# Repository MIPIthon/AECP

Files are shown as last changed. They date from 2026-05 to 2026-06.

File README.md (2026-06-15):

<h1>AECP (Analog Eddy Current Pickup)</h1>
Analog Eddy Current Pickup (AECP) is an analog eddy current signal conditioner circuit based on synchronous rectification of the amplitude of an LC tank circuit at resonance frequency. The circuit can be used to measure e.g. relative movement of a conductive or magnetic permeable object.

<h2>PCBA (Printed Circuit Board Assembly) </h2>

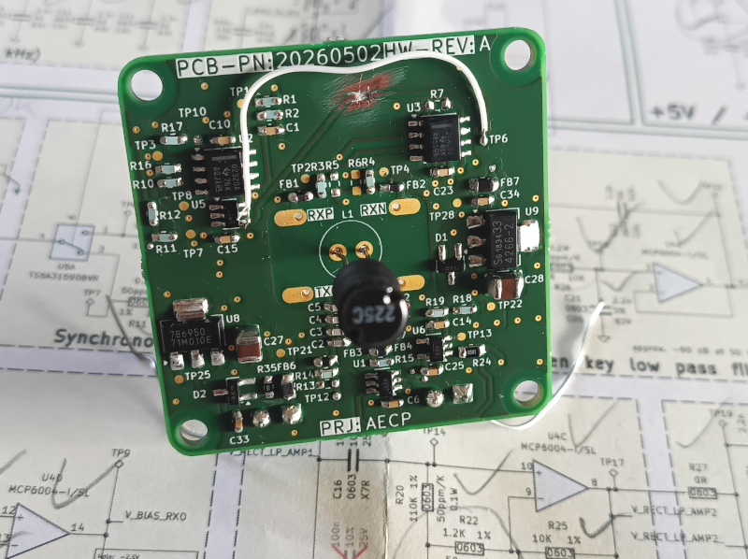
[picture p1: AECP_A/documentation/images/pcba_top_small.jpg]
AECP_A_PCB_TOP


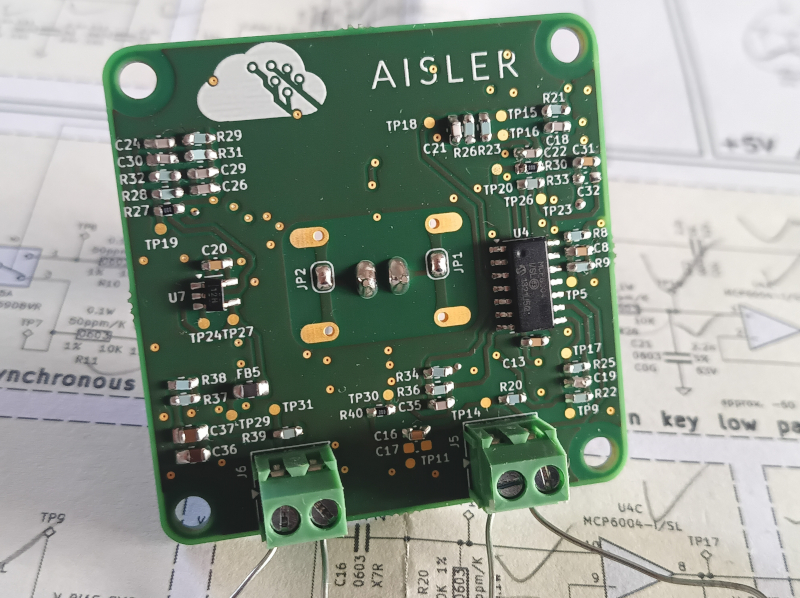
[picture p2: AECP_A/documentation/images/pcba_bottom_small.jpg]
AECP_A_PCB_BOTTOM


<h2>Known issues</h2>
- INA188 zero-drift chopper amplifier: Internal chopper (zero drift) is unnecessary and detrimental to the output noise of the circuit due to beat-frequencies generated caused by the chopper frequencies and the frequency content of the square wave synchronous rectifier. 

Potential fix: Replace INA188 with INA828 (no chopper). If the common-mode voltage is approximately VCM=2.5V, the LT1167 is a suitable alternative (e.g. if the the RX part of the circuit is not directly connected to TXI and TXO (VCM=2.5V))

  FFT average: ACOUT, NoTarget, INA disconnected => White noise
  grafik
  
  FFT average: ACOUT and TP6,  NoTarget, INA connected => White noise + beat frequency
  grafik
  
  FFT average: TXI, NoTarget => Very low distortion
  grafik
  
  Time domain: TP6 => Distortion
  grafik
  
  Time domain: TXI => No distortion
  grafik

<h2>Notes</h2>
- Notch filter intended to suppress the frequency component at two times the resonance frequency after rectification is not necessary. The currently used resistor and capacitor values are dummy values. 
grafik

<h2>Use Cases</h2>

- Guitar / musical instrument pickup
- Vibration sensing of metallic objects

<h2>Audio examples</h2>

https://github.com/user-attachments/assets/294e206a-773d-46ed-8725-847c0cfb6f45

https://github.com/user-attachments/assets/1e3492f7-05f8-4548-aefb-00401e7eae84

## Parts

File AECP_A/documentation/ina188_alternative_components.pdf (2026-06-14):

| INA188 | LT1167AI | INA828 | INA818 | AD8422

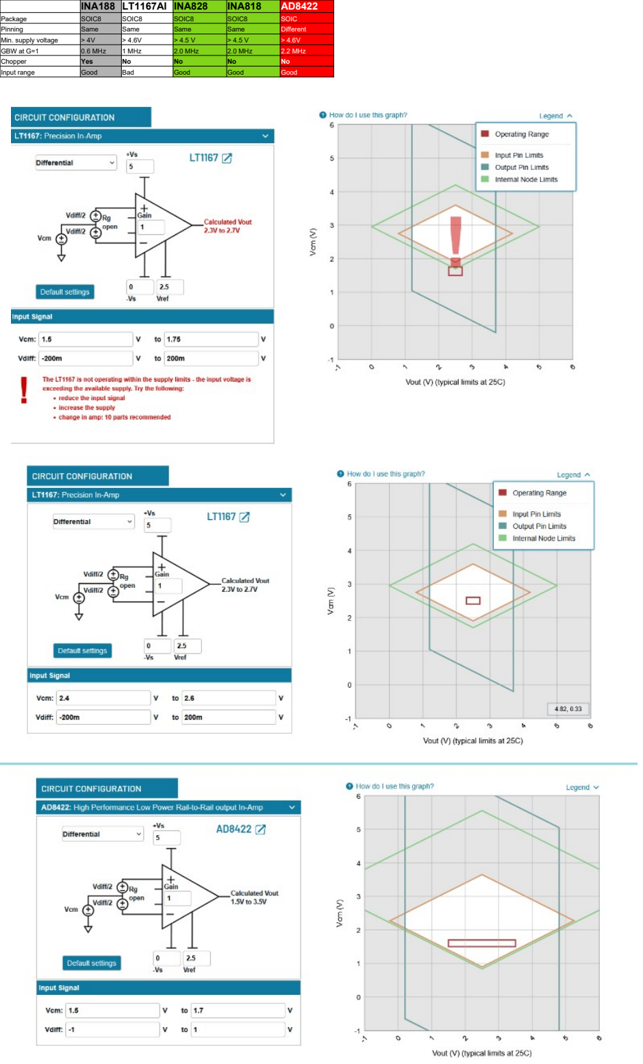
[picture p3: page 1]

Package | SOIC8 | SOIC8 | SOIC8 | SOIC8 | SOIC
Pinning | Same | Same | Same | Same | Different
Min. supply voltage | > 4V | > 4.6V | > 4.5 V | > 4.5 V | > 4.6V
GBW at G=1 | 0.6 MHz | 1 MHz | 2.0 MHz | 2.0 MHz | 2.2 MHz
Chopper | Yes | No | No | No | No
Input range | Good | Bad | Good | Good | Good

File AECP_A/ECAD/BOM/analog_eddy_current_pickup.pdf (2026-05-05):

Reference | Qty | Part number | Value | Manufacturer | Package | Rated power | Resistance | Tolerance | Type | Voltage | Drift
U9 | 1 | TLE42662GSV33HTMA2 | TLE42662GSV33HTMA2 | Infineon | SOT-223
U8 | 1 | TPS7B6950QDCYRQ1 | TPS7B6950QDCYRQ1 | Texas Instruments | SOT-223
U7 | 1 | TLV314IDBVR | TLV314IDBVR | Texas Instruments | SOT-23-5
U6 | 1 | TLV3201AIDBVR | TLV3201AIDBVR | Texas Instruments | SOT-23-5
U4 | 1 | MCP6004-I/SL | MCP6004-I/SL | Microchip | SOIC-14
U3 | 1 | INA188ID | INA188ID | Texas Instruments | SOIC-8
U2 | 1 | OPA2320AID | OPA2320AID | Texas Instruments | SOIC-8
U1,U5 | 2 | TS5A3159DBVR | TS5A3159DBVR | Texas Instruments | SOT-23-6
R27,R30,R35,R40 | 4 | CRCW06030000Z0EA | 0R | Vishay | 0603 | NA | | 0% | | | 0ppm/K
R24 | 1 | CRCW0805100RFKEA | 100R | Vishay | 0805 | 0.25W | | 1% | | | 100ppm/K
R5,R6,R20,R33,R39 | 5 | MCT06030C1103FP500 | 110K | Vishay | 0603 | 0.1W | | 1% | | | 50ppm/K
R3,R4,R13,R14,R15,R22,R28,R29,R31,R32,R34,R37,R38 | 13 | MCT06030C1201FP500 | 1.2K | Vishay | 0603 | 0.1W | | 1% | | | 50ppm/K
R1,R2,R7,R8,R9,R10,R11,R12,R16,R17,R18,R19,R21,R23,R25,R26,R36 | 17 | MCT06030C1002FP500 | 10K | Vishay | 0603 | 0.1W | | 1% | | | 50ppm/K
PCB1 | 1 | 20260502 | PCB_SILKSCREEN | AISLER | NA
L1 | 1 | 22R225C | 2.2m | Murata | NA | | | 10%
J5,J6 | 2 | YO0201500000G | YO0201500000G | Amphenol Anytek | NA
FB5,FB6,FB7 | 3 | 74279204 | 74279204 | Würth | 0805 | | 0.35R @DC
FB1,FB2,FB3,FB4 | 4 | BLM18AG102BH1D | BLM18AG102BH1D | Murata | 0805 | | 0.5R @DC
D2 | 1 | SBAS16LT1G | SBAS16LT1G | onsemi | SOT-23
D1 | 1 | BAS40-04 | BAS40-04 | Infineon | SOT-23
C36,C37 | 2 | GCM219R71C105KA37 | 1u | Murata | 0805 | | | 10% | X7R | 16V
C27,C28 | 2 | GCM32EC7YA106KA03 | 10u | Murata | 1210 | | | 10% | X7S | 35V
C2,C3,C4,C5,C7,C9,C11,C12,C18,C19,C21,C22,C24,C26,C29,C30,C35 | 17 | GCM1885C1J222JA16D | 2.2n | Murata | 0603 | | | 5% | C0G | 63V
C1,C6,C8,C10,C13,C14,C15,C16,C17,C20,C23,C25,C31,C32,C33,C34 | 16 | 06033C104K4T4A | 100n | Kyocera AVX | 0603 | | | 10% | X7R | 25V

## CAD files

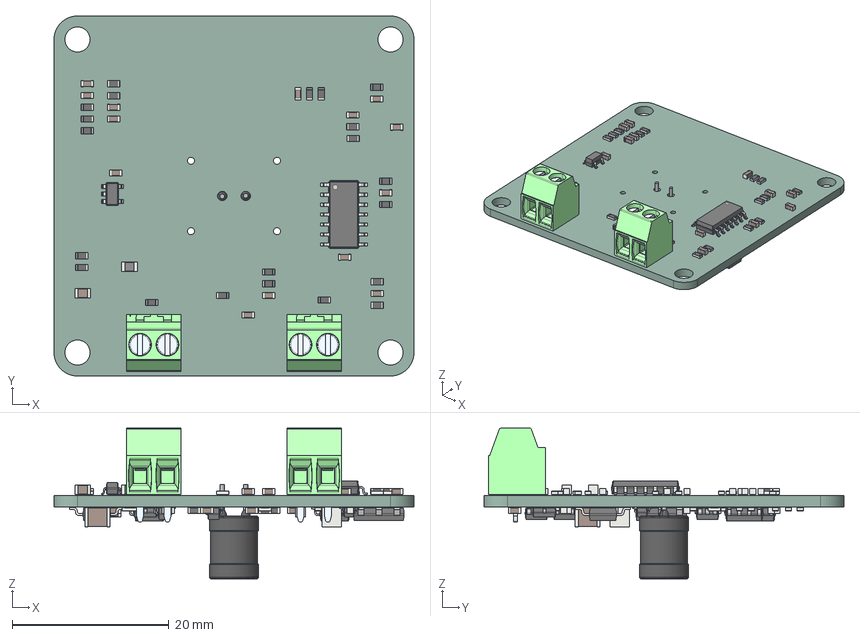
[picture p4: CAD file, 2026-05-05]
AECP_A/ECAD/3D_STEP/simple/analog_eddy_current_pickup_rev_A.step
46.0 x 46.0 x 19.2 mm
C_0603_1608Metric x 31
R_0603_1608Metric x 35
J_2P_3_5MM_1546551-2 x 2
SOT-23-5 x 2
FB_0805_2012Metric x 3
C_0805_2012Metric
SOIC-14_3.9x8.7mm_P1.27mm
FB_0603_1608Metric x 4
SOT-23-6 x 2
SOT-223 x 2
R_0805_2012Metric
SOIC-8_3.9x4.9mm_P1.27mm x 2
SOT-23 x 2
C_1210_3225Metric x 2
analog_eddy_current_pickup_PCB

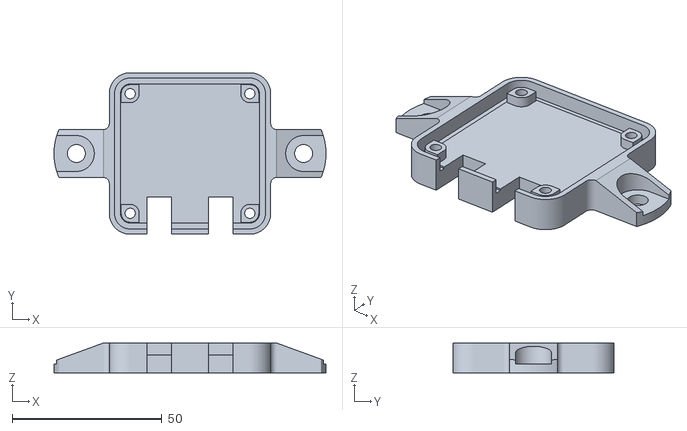
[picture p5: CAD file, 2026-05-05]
AECP_A/MCAD/housing_rev5-bottom_cover.stl
91.0 x 54.0 x 10.0

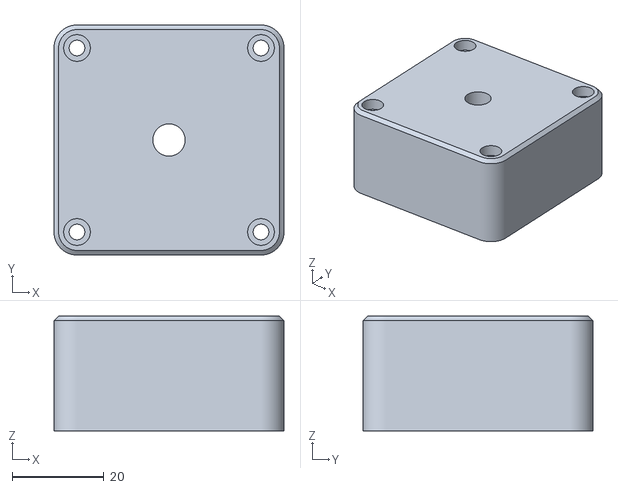
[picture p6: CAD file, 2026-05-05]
AECP_A/MCAD/housing_rev5-top_cover.stl
50.0 x 50.0 x 25.0

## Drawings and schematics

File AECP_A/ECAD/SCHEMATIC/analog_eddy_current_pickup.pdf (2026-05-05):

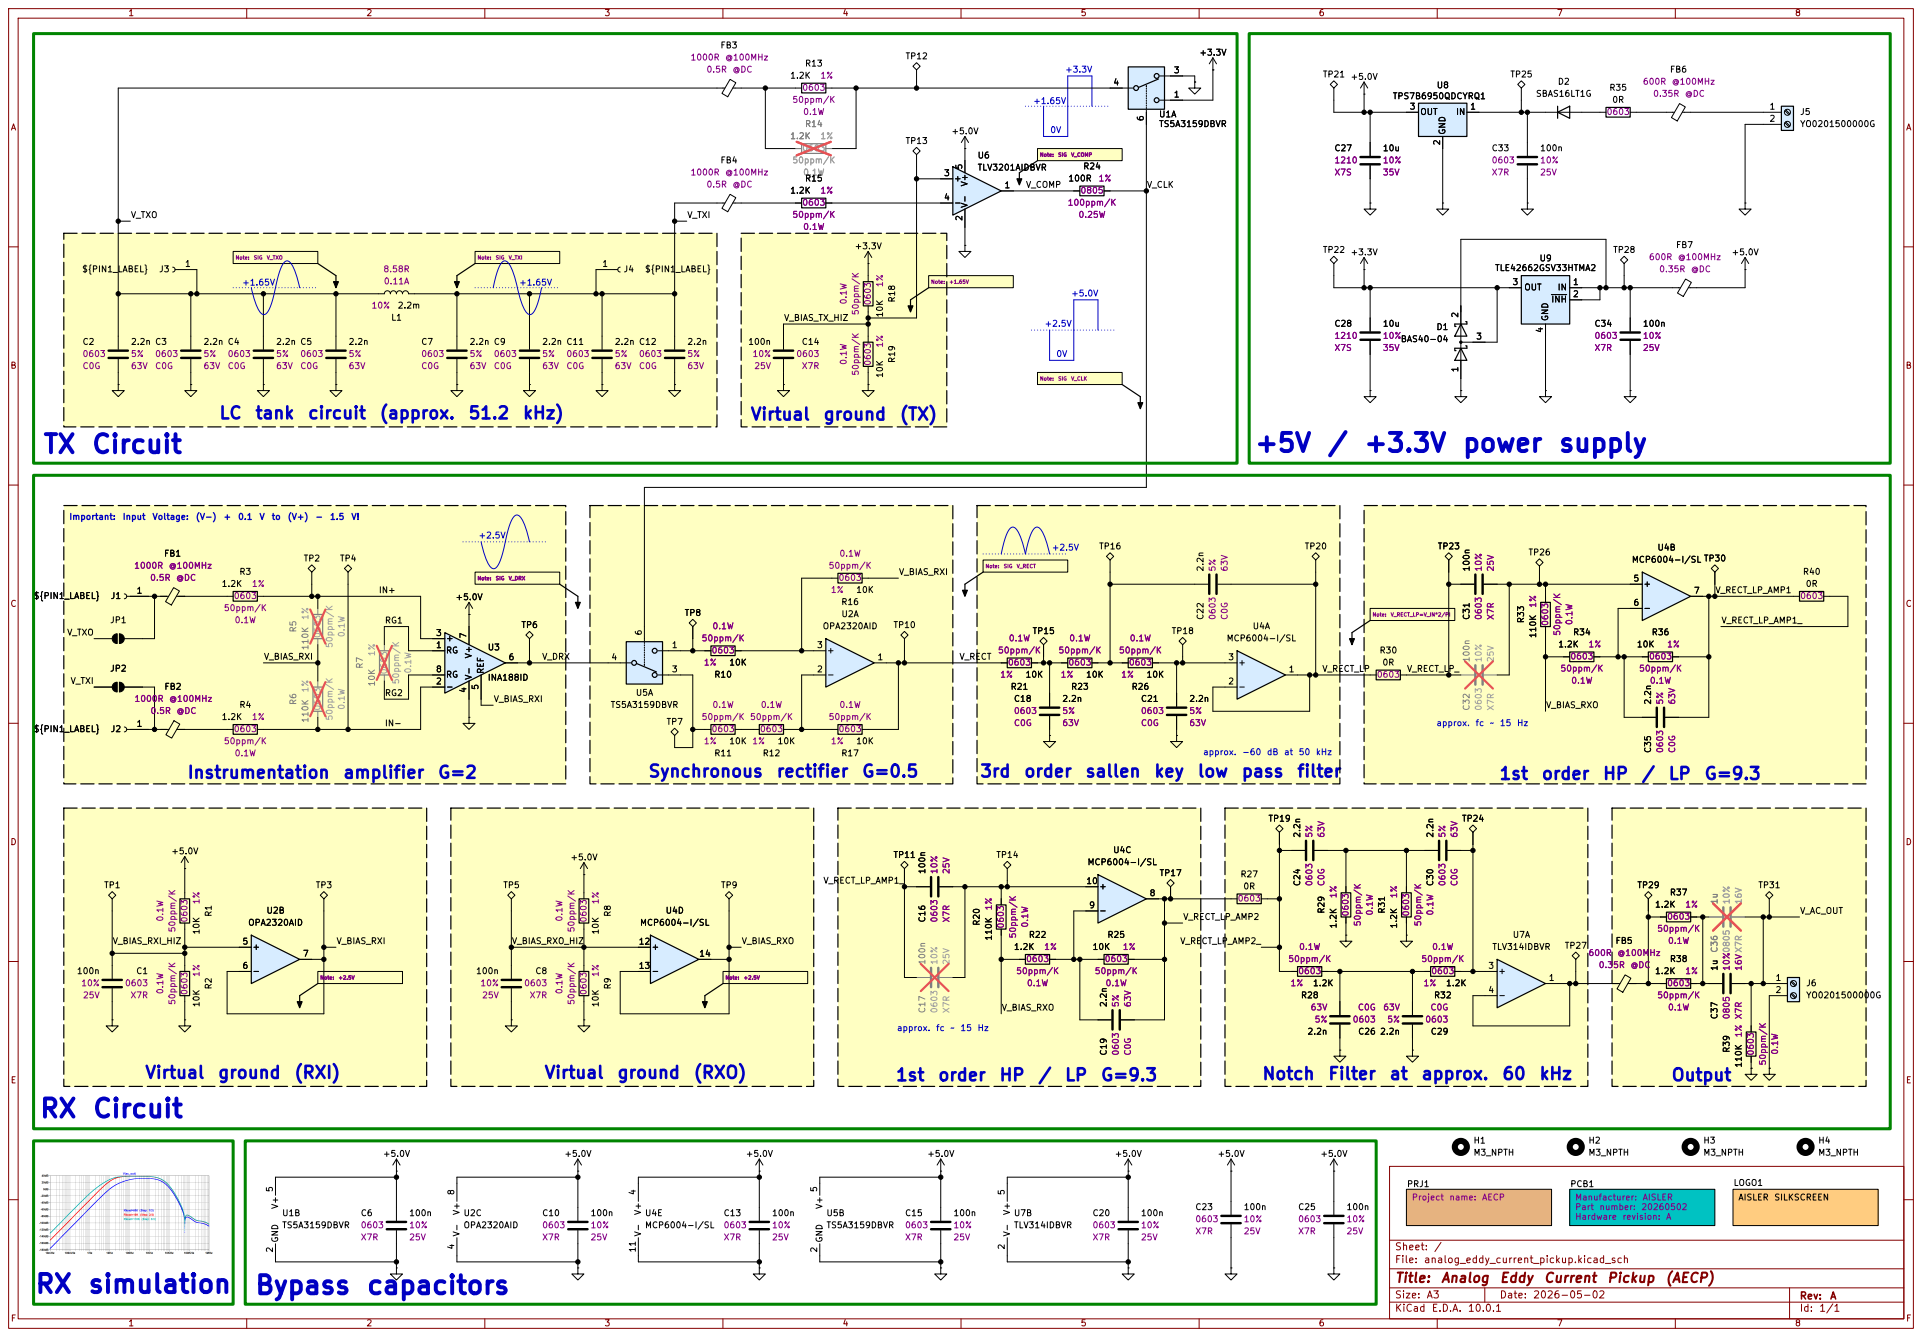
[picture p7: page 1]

+5.0V 0V 3rd order sallen key low pass filter

LC tank circuit (approx. 51.2 kHz)

approx. -60 dB at 50 kHz

approx. fc ~ 15 Hz Synchronous rectifier G=0.5

Notch Filter at approx. 60 kHz

Sheet: /
File: analog_eddy_current_pickup.kicad_sch
Title: Analog Eddy Current Pickup (AECP)

Size: A3 | Rev: A | F Date: 2026-05-02
KiCad E.D.A. 10.0.1 | Id: 1/1

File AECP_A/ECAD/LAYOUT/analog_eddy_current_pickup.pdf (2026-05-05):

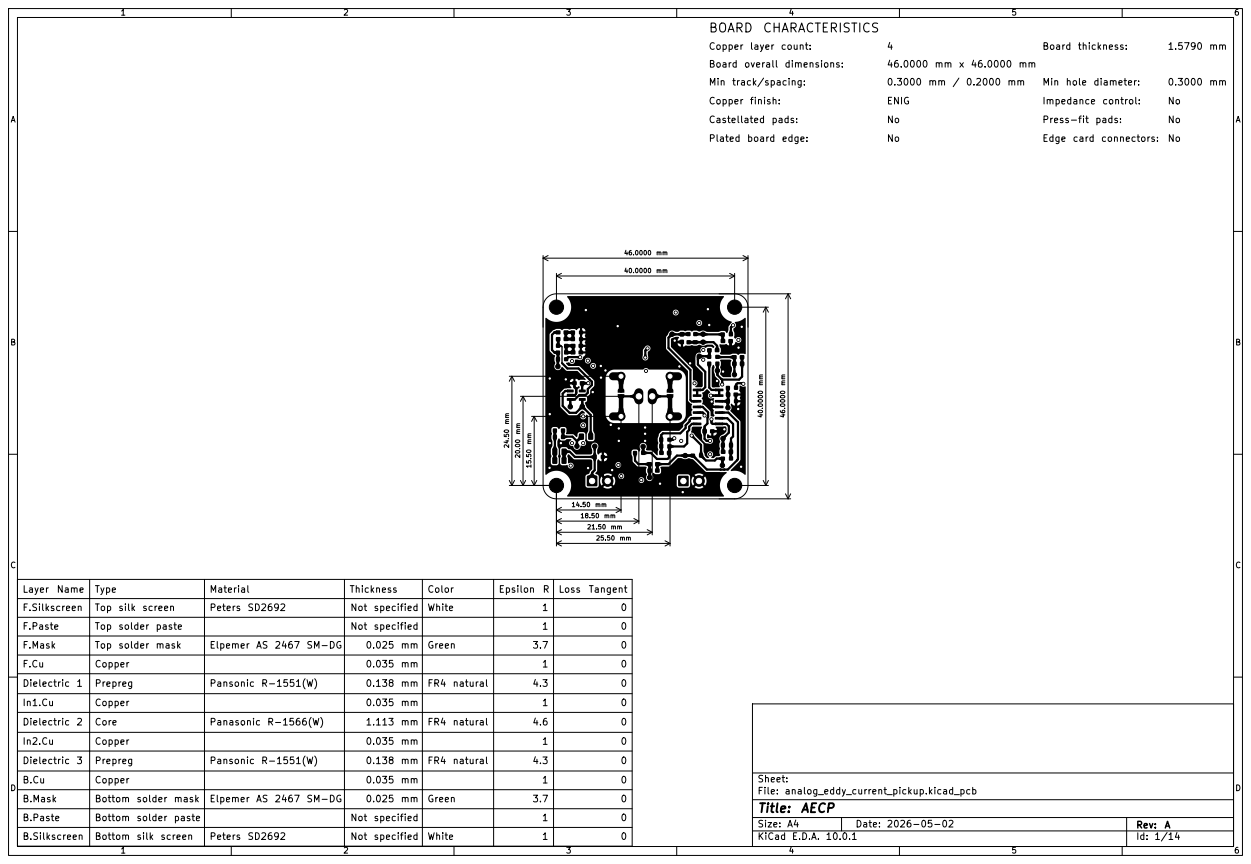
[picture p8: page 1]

Layer Name | Type | Material | Thickness | Color | Epsilon R | Loss Tangent
F.Silkscreen | Top silk screen | Peters SD2692 | Not specified | White | 1 | 0
F.Paste | Top solder paste | | Not specified | | 1 | 0
F.Mask | Top solder mask | Elpemer AS 2467 SM-DG | 0.025 mm | Green | 3.7 | 0
F.Cu | Copper | | 0.035 mm | | 1 | 0
Dielectric 1 | Prepreg | Pansonic R-1551(W) | 0.138 mm | FR4 natural | 4.3 | 0
In1.Cu | Copper | | 0.035 mm | | 1 | 0
Dielectric 2 | Core | Panasonic R-1566(W) | 1.113 mm | FR4 natural | 4.6 | 0
In2.Cu | Copper | | 0.035 mm | | 1 | 0
Dielectric 3 | Prepreg | Pansonic R-1551(W) | 0.138 mm | FR4 natural | 4.3 | 0

B.Mask | Bottom solder mask | Elpemer AS 2467 SM-DG | 0.025 mm | Green | 3.7 | 0
B.Paste | Bottom solder paste | | Not specified | | 1 | 0

Size: A4 | Rev: A
KiCad E.D.A. 10.0.1 | Id: 1/14

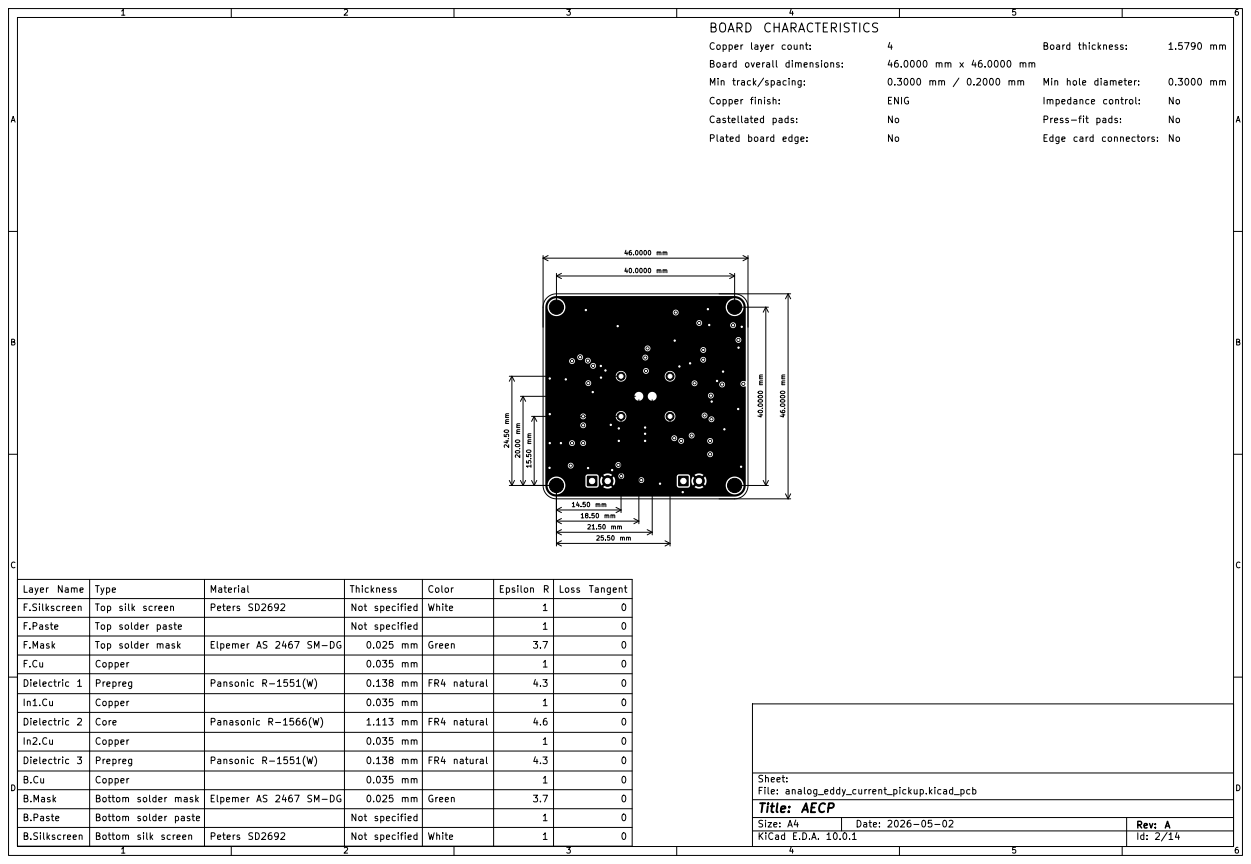
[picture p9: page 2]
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

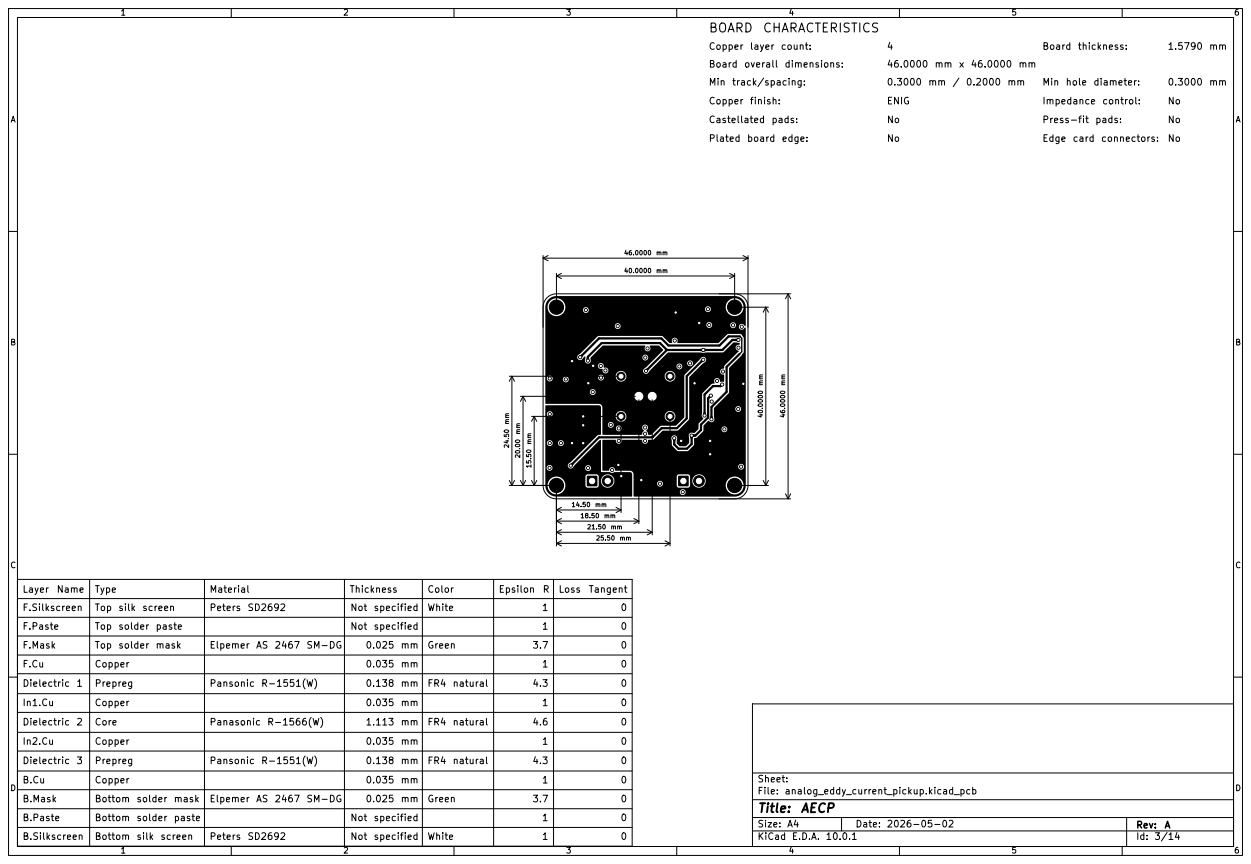
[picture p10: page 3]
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

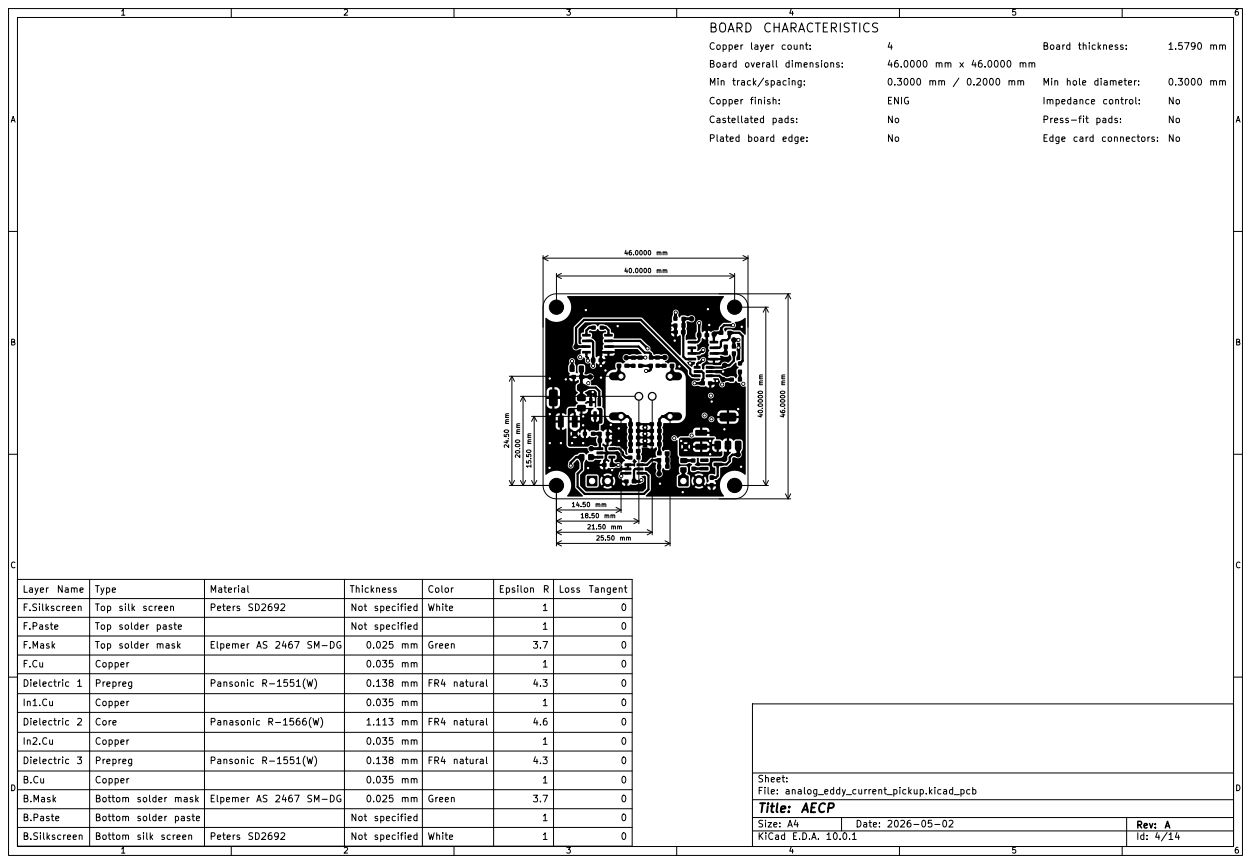
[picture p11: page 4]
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

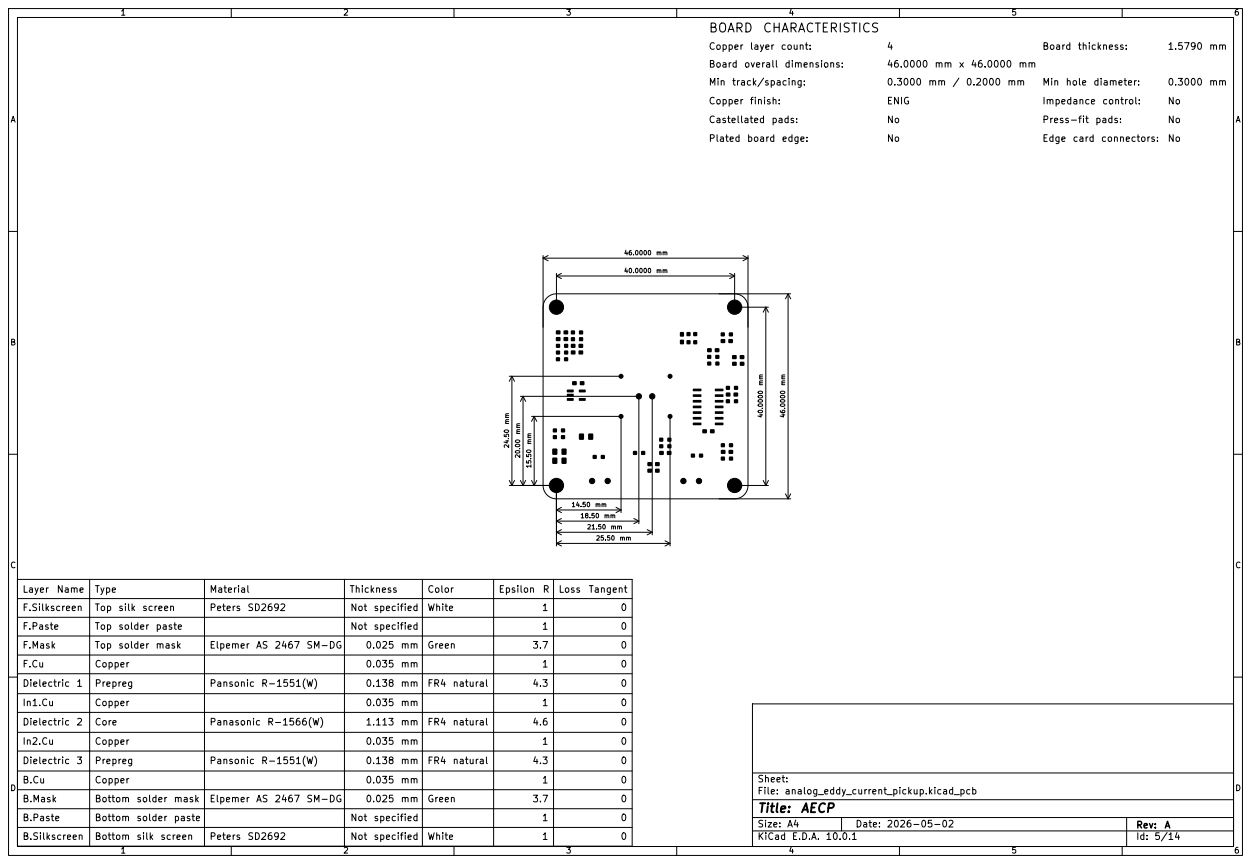
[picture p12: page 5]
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

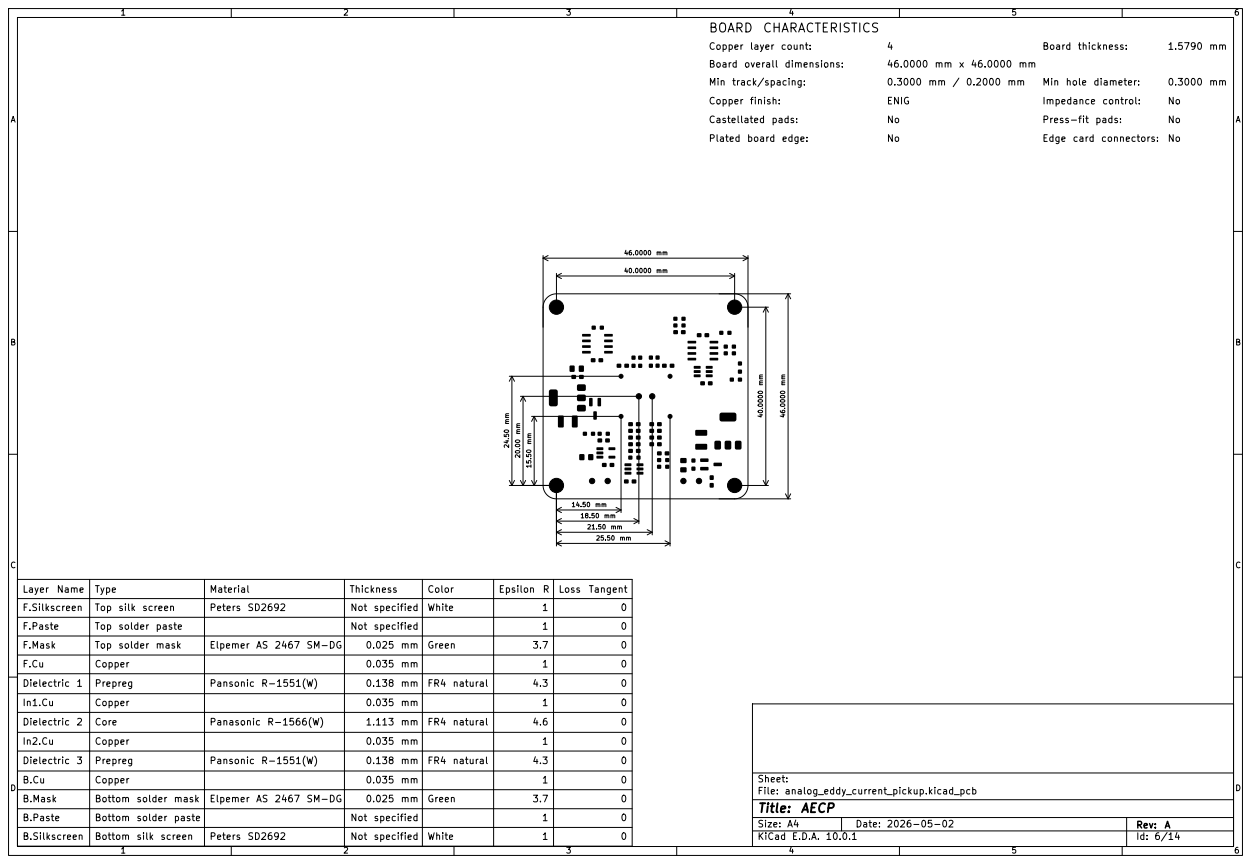
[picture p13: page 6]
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

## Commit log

2026-05-25 Update README with PCB images and use cases
    Added images of the PCB assembly and use cases for the AECP.
2026-06-15 Update README with clarification on notch filter
    Corrected wording for clarity regarding the notch filter and its necessity.
